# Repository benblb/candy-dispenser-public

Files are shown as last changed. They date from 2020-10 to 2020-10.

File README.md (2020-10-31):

# Contactless candy dispenser

This is the code and 3D print files associated with a 3D-printed candy dispenser created during COVID-19 Halloween. The program uses a sonar sensor for contactless candy distribution. 

# Code

Designed to run on a Node MCU, the program distributes one piece of candy and send the admin a Telegram message when candy is running low. The program is provided here for anyone who would like to make a similar (or exactly the same) machine. 

1) User holds hand in front of sonar sensor
2) Candy is pushed out front slot of enclosure using a rack + pinion driven by a stepper motor. LEDs animate as candy dispenses. 
3) User takes candy and machine waits for next sonar sensing. LEDs flash to indicate "ready" status. 

By default the sonar range is 15 cm. Digital pins 5 and 6 are used for the sonar sensor. Digital pins 1-4 are used for the stepper motor. Digital pin 8 is used for the LEDs. 

Equipment needed:
Node MCU
Stepper motor + driver board
Sonar sensor
Wires
5v power supply (aim for >1A), I used a USB cable that I soldered some pin connectors onto to make power and ground nodes.

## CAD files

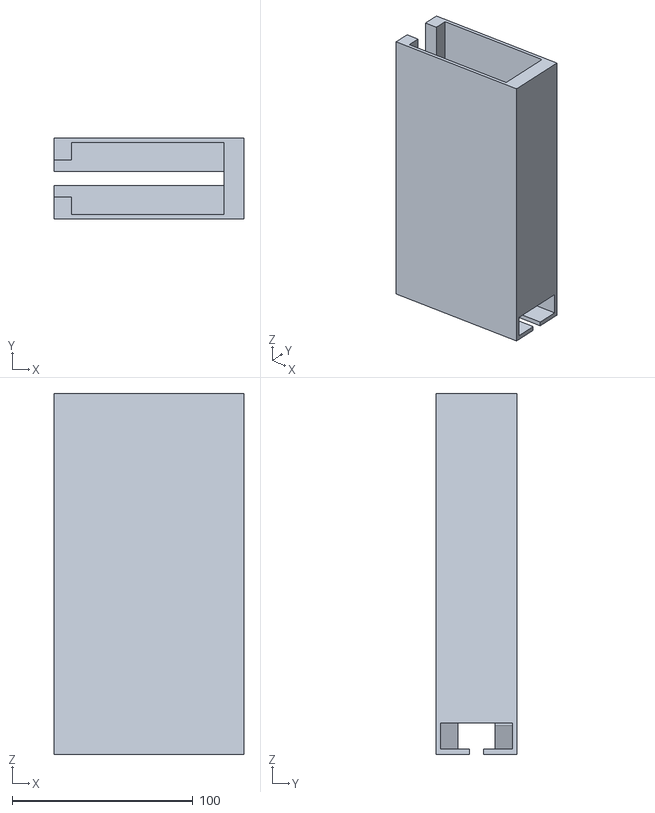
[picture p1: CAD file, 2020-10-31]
Magazine.stl
105.0 x 45.0 x 200.0

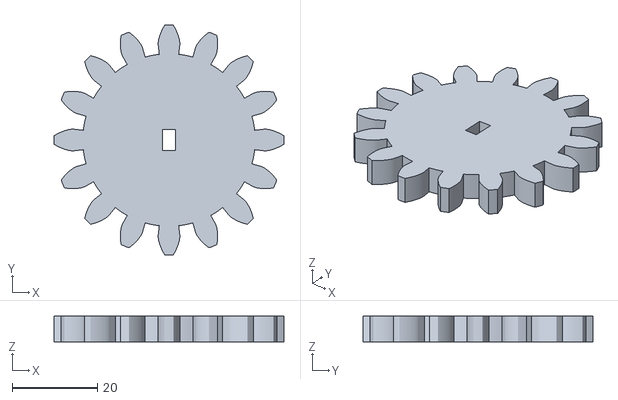
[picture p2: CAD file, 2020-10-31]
Gear.stl
54.0 x 54.0 x 6.00

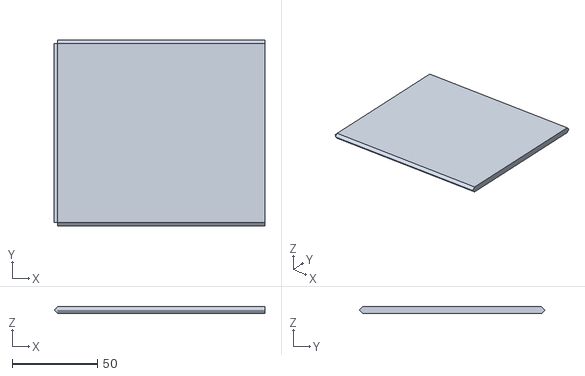
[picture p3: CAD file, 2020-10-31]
Door.stl
123.8 x 109.1 x 4.00

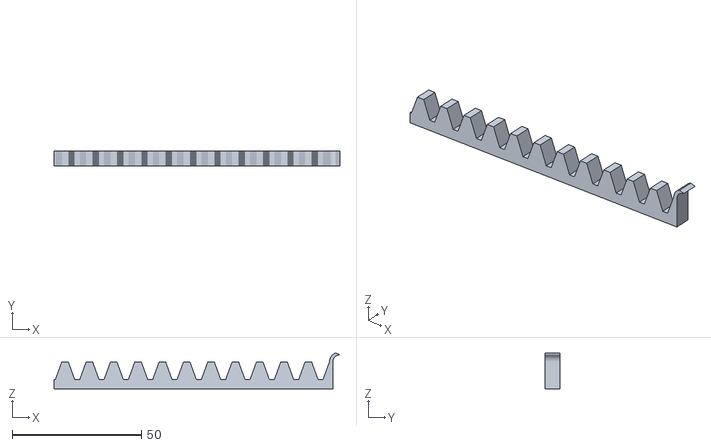
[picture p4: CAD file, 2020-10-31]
Rack.stl
110.8 x 5.80 x 13.9

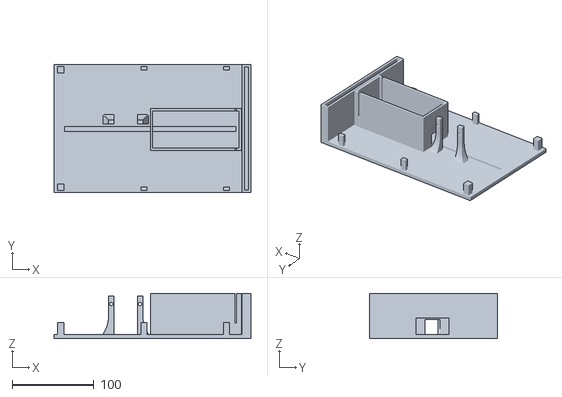
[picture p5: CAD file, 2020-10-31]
Base.stl
240.3 x 156.0 x 55.0

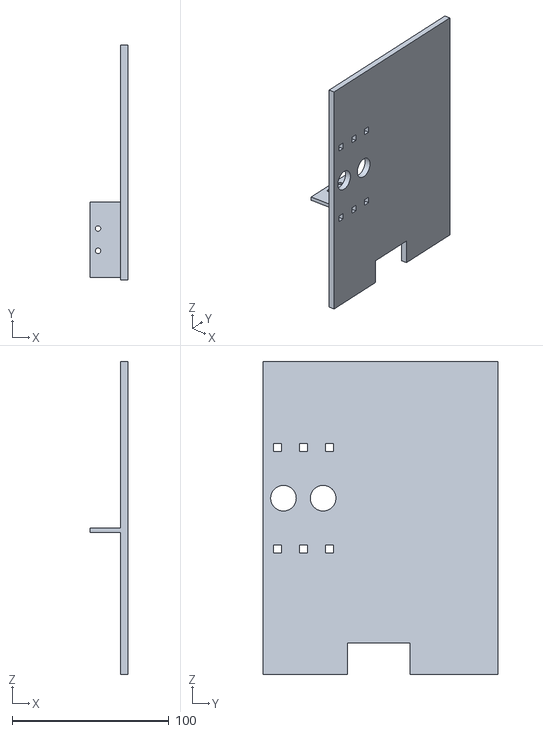
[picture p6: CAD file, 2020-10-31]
Face.stl
24.5 x 150.0 x 200.0

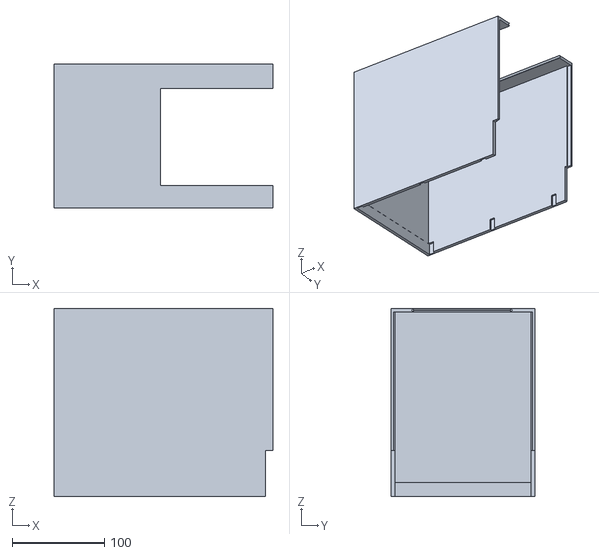
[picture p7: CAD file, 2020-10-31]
Cover.stl
237.5 x 156.0 x 204.0

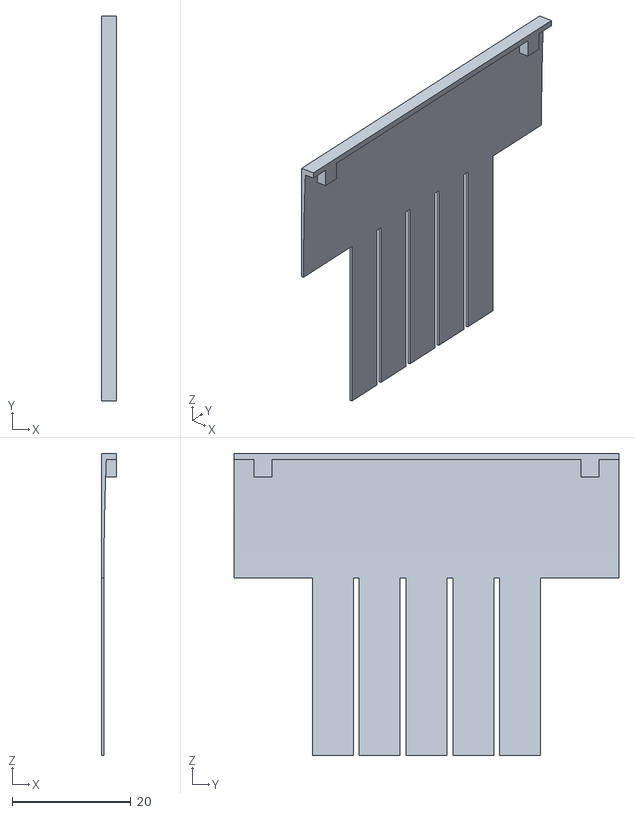
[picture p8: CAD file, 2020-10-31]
Flaps.stl
2.50 x 65.0 x 51.0

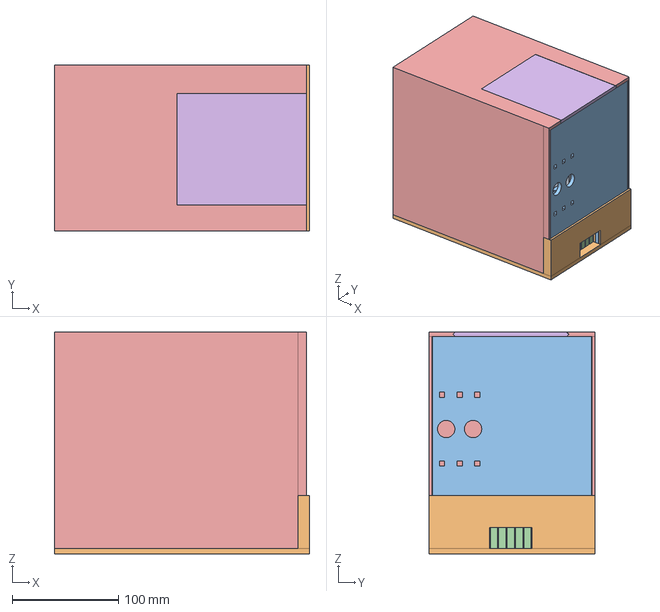
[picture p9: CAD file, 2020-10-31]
Holloween Candy Dispenser Public v2.step
240.3 x 156.0 x 209.0 mm

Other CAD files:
Candy Dispenser Rack Public v2.step

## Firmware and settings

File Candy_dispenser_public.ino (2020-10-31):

#include "CTBot.h"
#define FASTLED_ESP8266_RAW_PIN_ORDER
#include <FastLED.h>

// LED setup
#define NUM_LEDS 6
#define DATA_PIN D8
int whichLED = 0; 

// Define the array of leds
CRGB leds[NUM_LEDS];

//Telegram bot setup
CTBot myBot;
TBMessage msg;
int candyCount = 20;  // Reboot device to reset candy counter (takes ~5 secs), change this value based on number of candies you load

//WiFi auth, Telegram bot token
String ssid = "WIFI_SSID_GOES_HERE";
String pass = "WIFI_PASSWORD_GOES_HERE";
String token = "TELEGRAM_BOT_TOKEN_GOES_HERE";  

//Stepper motor, digital pins 1-4
int Pin1 = D1; 
int Pin2 = D2; 
int Pin3 = D3; 
int Pin4 = D4; 
int _step = 0; 
bool dir = true;// false=clockwise, true=counter clockwise
int count=0;

//Sonar, digital pins 5 and 6
int trigPin = D5;
int echoPin = D6;
float duration, distance; 
int detected = 0;
int handDist = 15;

void setup() {
   
 Serial.begin(115200);

 FastLED.addLeds<WS2812B, DATA_PIN, GRB>(leds, NUM_LEDS);  // GRB ordering is typical
    
 pinMode(Pin1, OUTPUT);  
 pinMode(Pin2, OUTPUT);  
 pinMode(Pin3, OUTPUT);  
 pinMode(Pin4, OUTPUT);  

 pinMode(trigPin, OUTPUT); 
 pinMode(echoPin, INPUT); 

 //Connect the ESP8266 to the desired access point
 myBot.wifiConnect(ssid, pass);

  //Set the telegram bot token
 myBot.setTelegramToken(token);
} 

void loop(){

 // LED waiting flash
  for(int i = 0; i < NUM_LEDS; i++)
  {
    leds[i] = CHSV(8, 255, 100);
  }
  FastLED.show();
  delay(500);

  for(int i = 0; i < NUM_LEDS; i++)
  {
    leds[i] = CHSV(8, 255, 50);
  }
  FastLED.show();

 // Sonar pulse
 digitalWrite(trigPin, LOW); 
 delayMicroseconds(2); 
 digitalWrite(trigPin, HIGH); 
 delayMicroseconds(10); 
 digitalWrite(trigPin, LOW); 

 duration = pulseIn(echoPin, HIGH); 
 distance = (duration*.0343)/2; 


 // Turn motor to dispense candy
 // Full motor rotation is 4096
 if(distance < handDist && detected == 0)
 {
    // Optional anti-covering check, prevents continuous candy dispensing, slows user experience
    // detected = 1;
    whichLED = 0;

    // LEDs off
    for(int i = 0; i < NUM_LEDS; i++)
    {
      leds[i] = CHSV(0, 0, 0);
    }
    FastLED.show();
      
    dir = true;
    for(int i = 0; i < 2048; i++) 
    {
      turn();
      delay(2);
      if(i % 200 == 0)
      {
        circle();
      }
    }
    dir = false;
    for(int i = 0; i < 2048; i++)
    {
      turn();
      delay(2);
      if(i % 200 == 0)
      {
        circle();
      }
    }

     digitalWrite(Pin1, LOW);  
     digitalWrite(Pin2, LOW); 
     digitalWrite(Pin3, LOW); 
     digitalWrite(Pin4, LOW); 

     candyCount = candyCount - 1;
     // Notify when 3 pieces are left
     if(candyCount == 3)
     {
        for(int i = 0; i < NUM_LEDS; i++)
        {
          leds[i] = CHSV(0, 255, 100);
        }
        FastLED.show();

        // Replace "1234567890" with your Telegram user number. This can be found using the get IDs bot
        myBot.sendMessage(1234567890, String(candyCount));
     }
  }

// Optional anti-covering check
/*
 digitalWrite(trigPin, LOW); 
 delayMicroseconds(2); 
 digitalWrite(trigPin, HIGH); 
 delayMicroseconds(10); 
 digitalWrite(trigPin, LOW); 

 duration = pulseIn(echoPin, HIGH); 
 distance = (duration*.0343)/2; 

  if(distance > handDist)
  {
    detected = 0;
  }
*/

  // Delay needed for FastLED
  delay(500);
}


void turn() 
{ 
 switch(_step){ 
   case 0: 
     digitalWrite(Pin1, LOW);  
     digitalWrite(Pin2, LOW); 
     digitalWrite(Pin3, LOW); 
     digitalWrite(Pin4, HIGH); 
   break;  
   case 1: 
     digitalWrite(Pin1, LOW);  
     digitalWrite(Pin2, LOW); 
     digitalWrite(Pin3, HIGH); 
     digitalWrite(Pin4, HIGH); 
   break;  
   case 2: 
     digitalWrite(Pin1, LOW);  
     digitalWrite(Pin2, LOW); 
     digitalWrite(Pin3, HIGH); 
     digitalWrite(Pin4, LOW); 
   break;  
   case 3: 
     digitalWrite(Pin1, LOW);  
     digitalWrite(Pin2, HIGH); 
     digitalWrite(Pin3, HIGH); 
     digitalWrite(Pin4, LOW); 
   break;  
   case 4: 
     digitalWrite(Pin1, LOW);  
     digitalWrite(Pin2, HIGH); 
     digitalWrite(Pin3, LOW); 
     digitalWrite(Pin4, LOW); 
   break;  
   case 5: 
     digitalWrite(Pin1, HIGH);  
     digitalWrite(Pin2, HIGH); 
     digitalWrite(Pin3, LOW); 
     digitalWrite(Pin4, LOW); 
   break;  
     case 6: 
     digitalWrite(Pin1, HIGH);  
     digitalWrite(Pin2, LOW); 
     digitalWrite(Pin3, LOW); 
     digitalWrite(Pin4, LOW); 
   break;  
   case 7: 
     digitalWrite(Pin1, HIGH);  
     digitalWrite(Pin2, LOW); 
     digitalWrite(Pin3, LOW); 
     digitalWrite(Pin4, HIGH); 
   break;  
   default: 
     digitalWrite(Pin1, LOW);  
     digitalWrite(Pin2, LOW); 
     digitalWrite(Pin3, LOW); 
     digitalWrite(Pin4, LOW); 
   break;  
 } 
 if(dir){ 
   _step++; 
 }else{ 
   _step--; 
 } 
 if(_step>7){ 
   _step=0; 
 } 
 if(_step<0){ 
   _step=7; 
 } 
 delay(1); 

}

void circle()
{
  leds[whichLED] = CHSV(8, 255, 100);

  FastLED.show();
  
  leds[whichLED] = CHSV(8, 255, 50);

  whichLED = whichLED + 1;
  
  if(whichLED == 6)
  {
    whichLED = 0;
  }
}

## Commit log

2020-10-31 Update Candy_dispenser_public.ino
    Slowed motor for more torque, weight of 20 candies is a bit too much for faster speed (motor was slipping). Good thing Halloween doesn't start in an hour...
    [Candy_dispenser_public.ino]
2020-10-31 Add files via upload
    CAD and STL files by Gabe Baranovsky
    [Base.stl, Candy Dispenser Rack Public v2.step, Cover.stl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]
